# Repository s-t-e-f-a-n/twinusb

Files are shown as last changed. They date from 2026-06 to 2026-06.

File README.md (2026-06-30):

# H₂H³ | Twin USB Host Switch × Triple USB Hub (with OLED Telemetry)

**H₂H³** is a compact, STM32 microcontroller-driven USB 2.0 KVM switch and 3-port hub designed to maintain a clean, clutter-free workspace in modern home offices. It enables two computers to seamlessly share a single set of peripherals—like your keyboard, mouse, and flash drives—while delivering live voltage and current telemetry via an integrated OLED display.

<p align="center">
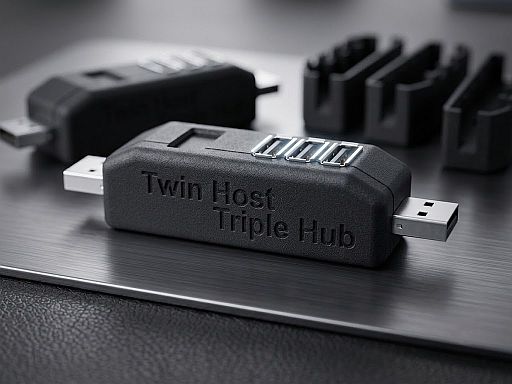
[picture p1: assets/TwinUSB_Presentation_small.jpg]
H₂H³ Presentation
  
</p>

> [!NOTE]
> **Project Status & Contribution:** This project is actively developed. The initial commit delivers roughly 90% of the core KVM switching and telemetry functionality in a fully functional prototype stage.
>
> To bring this project to a 100% polished release, **contributions from the open-source community are highly welcome!** Whether you want to optimize edge-case handling in the C++ firmware, implement new USB HID features, or help refine the documentation—feel free to open an issue or submit a Pull Request. Let's build this together!

* **Smart Break-Before-Make Switching:** Advanced, software-controlled VBUS and data line multiplexing ensures safe, glitch-free transitions and isolated power rails between both host PCs.
* **Integrated 3-Port Hub:** Built-in Genesys Logic controller expands a single shared USB connection into three downstream ports for your everyday desk peripherals.
* **🚀 Native Host-MCU Communication (Endless Use Cases!):** Unlike dumb KVM switches, the onboard STM32 MCU is wired directly into the hub as a **fourth USB peripheral device**. This allows the MCU to communicate natively with the active Host PC—opening up vast possibilities for custom PC desktop apps, background telemetry logging, hardware automation scripts, or even full USB HID keyboard/mouse emulation.
* **Live Telemetry Dashboard:** A crisp, integrated 64x32 pixel OLED display provides real-time insights by showing live bus voltage and precise current draw per port.
* **Ergonomic & Screw-less Enclosure:** Features a clean interface with a discreetly placed rear tactile button to prevent cable snags, all housed in a robust, snap-fit PA12-HP Nylon shell optimized for MJF 3D printing.
* **Modern C++ Firmware:** Driven by a powerful STM32G0 architecture running a modular, object-oriented C++ firmware stack with hardware-level overcurrent protection.

🖼️ Jump straight to the [Photo Gallery](#-photo-gallery).

🏪 **Hardware Available:** Skip the assembly line and grab a fully functional H₂H³ on [Tindie](https://www.tindie.com/products/43013/).

## 🔭 Background & Philosophy

H₂H³ represents a personal exploration into modern decentralized manufacturing and open-source engineering. It blends professional design principles with modern open-source software, AI-collaborative programming to refine the C++ firmware, and on-demand fabrication. The fact that an individual engineer can now prototype industrial-grade hardware using low-volume far-east manufacturing is nothing short of incredible.

To give back to the community, the full design files—spanning schematics, mechanics, and source code—are public domain under MIT and CERN Open Hardware licenses. It is intended strictly for educational use, and community-driven remixes are highly encouraged.

## 🛠️ Design Stack & Toolchain

The hardware, enclosure, and software for H₂H³ were designed using the following tools:

* **KiCad 9.0:** Schematic entry and PCB design for the 4-layer board.
* **FreeCAD 1.0:** 3D modeling of the screw-less, snap-fit two-part enclosure.
* **Firmware Toolchain:** Developed in modern modular C++ utilizing **STM32CubeMX** for hardware abstraction. Out of the box, the repository supports a dual-development workflow—you can build and debug the firmware seamlessly using either **Visual Studio Code (via CMake/Ninja)** or **STM32CubeIDE**, depending on your preferred environment.

---

## 🛠️ Hardware Specification

H₂H³ Hardware Block Diagram

* **Microcontroller:** ARM Cortex-M0+ 32-bit MCU (STM32G0B1KBU6, 64 MHz, 128 KB Flash, 144 KB RAM), integrated as a 4th peripheral on the hub.
* **USB 2.0 Hub Controller:** Genesys Logic GL852G.
* **Physical Interface:** * 2x USB-A Male (Host 1 / Host 2 connections)
  * 3x USB-A Female (Peripheral downstream ports)
* **Telemetry Sensors:** Continuous dual-host VBUS voltage sensing (enables auto-detection) and triple-peripheral current monitoring.
* **Switching Architecture:** Hybrid automatic/software-controlled VBUS muxer combined with hardware USB data line multiplexers.
* **User Interface:** 64x32 pixel OLED screen, 1x rear tactile switch button, and 1x fully programmable RGB LED (color and brightness).
* **Form Factor:** Ultra-compact desktop footprint (approx. 60 × 20 × 20 mm).

<table border="0" style="border: none; border-collapse: collapse;">
  <tr>
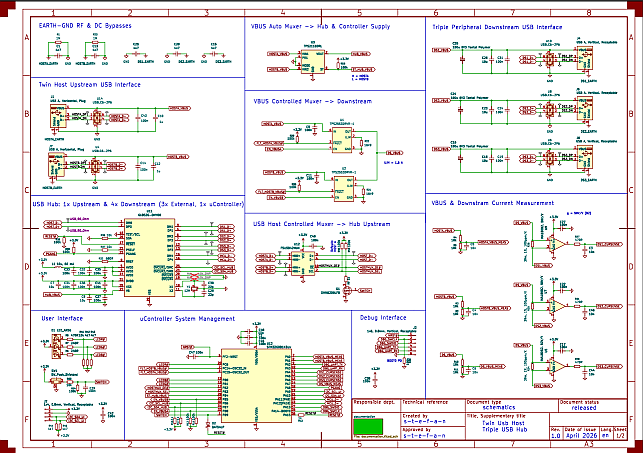
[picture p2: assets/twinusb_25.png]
    <td style="border: none; padding: 10px;"></td>
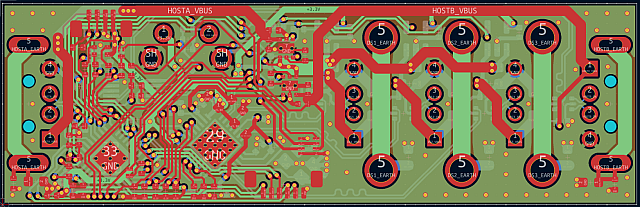
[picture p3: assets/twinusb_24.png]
    <td style="border: none; padding: 10px;"></td>
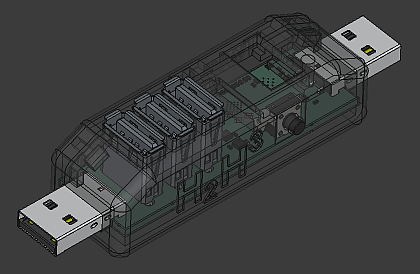
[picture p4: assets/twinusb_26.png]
    <td style="border: none; padding: 10px;"></td>
  </tr>
</table>

---

## 💻 Software & Firmware Architecture

The firmware is built using **STM32CubeMX** for hardware abstraction and written in **C/C++**.

### Advanced Features

* **Fully Modularized C/C++:** Source code is designed fully modular in C++ with support from the HAL in C automatically created by STM32CubeMX.
* **Optimized ADC Sampling:** Continuous monitoring of port power states with software-side calibration.
* **Overcurrent Detection:** Peripheral current draw of more than 1.5 A enters fault mode which the device resumes from by user confirmation.
* **UART Debug Console:** Retargeted `printf` over the STM32 USART2 or USB virtual COM port.
* **Binary Programming:** Powering on and holding switch button simultaneously enters the programming mode (STM32CubeProgrammer) which enables programming the ST32 integrated flash without the need for a hardware debugger

---

## 📂 Repository Structure

```text
twinusb/
├── assets/                  # Public media & documentation images
├── enclosure/               # Mechanical 3D CAD design (FreeCAD)
├── firmware/                # Production-ready STM32G0 C/C++ firmware
│   ├── App/                 # Core Application Logic (C++)
│   │   ├── Inc/             # Application Managers (Hub, Display, Sensors, UI)
│   │   └── Src/             # Implementation source code
│   ├── Core/                # Hardware peripheral initialization (ADC, I2C, GPIO)
│   ├── cmake/               # Toolchain configuration profiles
│   ├── Libs/                # Embedded drivers & hardware abstraction libraries
│   │   └── oled_waveshare/  # Low-level 0.49" 64x32 OLED display driver components
│   ├── Middlewares/         # STMicroelectronics USB Device Library stack
│   ├── Startup/             # Microcontroller boot vector assembly code
│   └── USB_Device/          # USB CDC Class configuration and descriptor maps
└── hardware/                # Electronics engineering files (KiCad)
    ├── lib_fp/              # Custom PCB footprint libraries (.pretty)
    └── lib_sch/             # Custom schematic component symbols
```

---

## ⚡ Getting Started & Building the Firmware

### 1. Cloning the Repository

```bash
git clone https://github.com/s-t-e-f-a-n/twinusb.git
cd twinusb

```

This project supports a **dual-development workflow**. You can build the firmware using either **VS Code (via CMake)** or the official **STM32CubeIDE**. Choose the workflow that best fits your environment. You do not need to use STM32CubeMX to build the project from scratch.

---

### Method A: Building with VS Code (Recommended)

This method uses CMake and Ninja/Make. It requires a local ARM GCC toolchain installed on your system.

#### Prerequisites

Ensure you have the following installed and available in your system's `PATH`:

* **ARM GNU Toolchain:** `arm-none-eabi-gcc`
* **Build Tools:** `CMake` and `Ninja` (or `Make`)
* **VS Code Extensions:**
* [CMake Tools](https://marketplace.visualstudio.com/items?itemName=ms-vscode.cmake-tools)
* [C/C++ Extension Pack](https://marketplace.visualstudio.com/items?itemName=ms-vscode.cpptools-extension-pack)

#### VS Code Setup & Build Steps

1. **Open Project:** Open the `firmware` directory in VS Code.
2. **Select Compiler Kit:** Open the Command Palette (`Ctrl+Shift+P` / `Cmd+Shift+P`), search for **`CMake: Select a Kit`**, and select your installed `arm-none-eabi` compiler.
3. **Select Build Variant:** Choose either `Debug` or `Release` from the CMake status bar at the bottom.
4. **Configure Project:** Run **`CMake: Configure`** from the Command Palette. This will clean-room generate your local `build/` directory with the correct absolute paths for your machine.
5. **Compile:** Click **`Build`** in the status bar or press `F7`.

---

### Method B: Building with STM32CubeIDE

STM32CubeIDE is an all-in-one Eclipse-based IDE that includes its own compiler toolchain and internal build system out of the box.

#### STM32CubeIDE Setup & Build Steps

1. **Import Project:**

* Open STM32CubeIDE.
* Go to `File` ➔ `Open Projects from Filesystem...`
* Select `Directory` ➔ `Choose twinusb folder` and click *Select Folder*.
* Click *Finish*.

2. **Index Project:** Wait a few moments for the IDE to finish indexing the source files.

3. **Compile:** Click the **Hammer icon (Build)** in the top toolbar, or press `Ctrl+B` (`Cmd+B` on macOS).

---

### ⚠️ Crucial Note on Code Generation (C++ Integration)

The core application logic of this project is written in modern **C++** and lives inside the `App/` directory (`App/Src` and `App/Inc`), keeping it cleanly decoupled from the autogenerated ST HAL layer.

If you decide to open the `twinusb.stm32.ioc` file to modify pinouts or peripherals via STM32CubeMX and click **"Generate Code"**, the tools will reset the project workspace to ST's default pure-C template.

**If your IDE loses track of the C++ files after code generation, fix it manually:**

* **In STM32CubeIDE:** Right-click the project ➔ `Properties` ➔ `C/C++ General` ➔ `Paths and Symbols`.
* Under **Includes**, re-add the `App/Inc` directory.
* Under **Source Location**, re-add the `App/Src` directory.

* **In VS Code:** Simply run **`CMake: Delete Cache and Reconfigure`** from the Command Palette to force CMake to re-scan the file structure.

---

## 🏭 Sourcing the Hardware

### PCB & Assembly

The schematics and PCB layout are located in the `/hardware` folder, designed in KiCad and optimized for automated assembly (PCBA) via services like JLCPCB.

### Enclosure

Print the shell components located in the `/enclosure` folder. Nylon (SLS/MJF technique) is highly recommended for that professional, textured matte finish and mechanical durability.

---

## 📸 Photo Gallery

| &nbsp; | &nbsp; | &nbsp; |
| :---: | :---: | :---: |
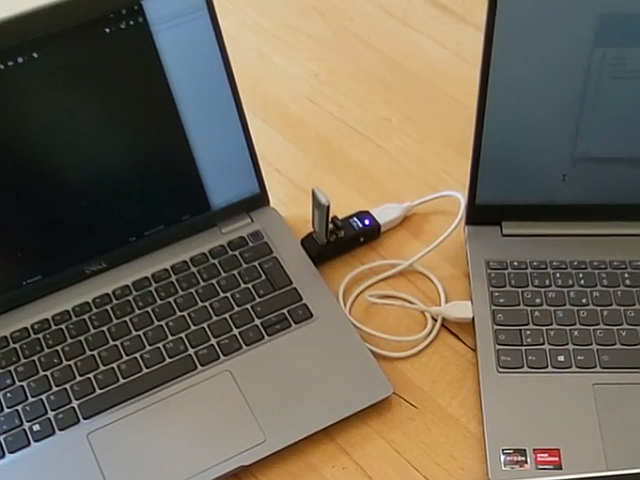
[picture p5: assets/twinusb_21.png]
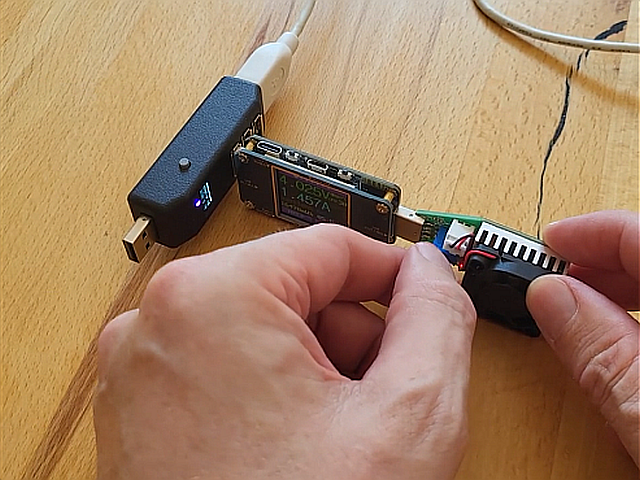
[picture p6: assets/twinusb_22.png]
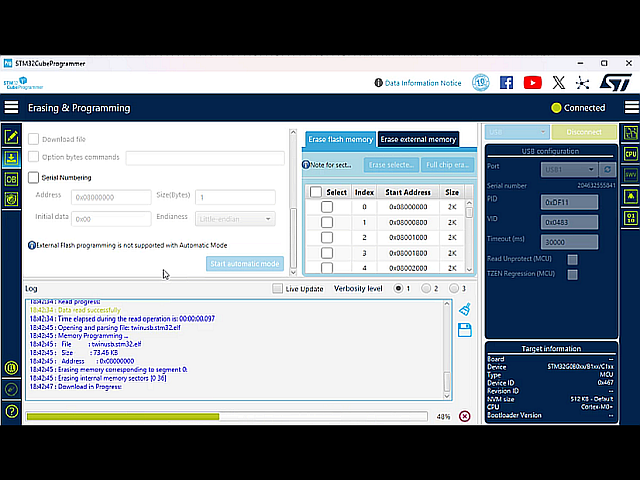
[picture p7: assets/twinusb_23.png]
|  |  |  |
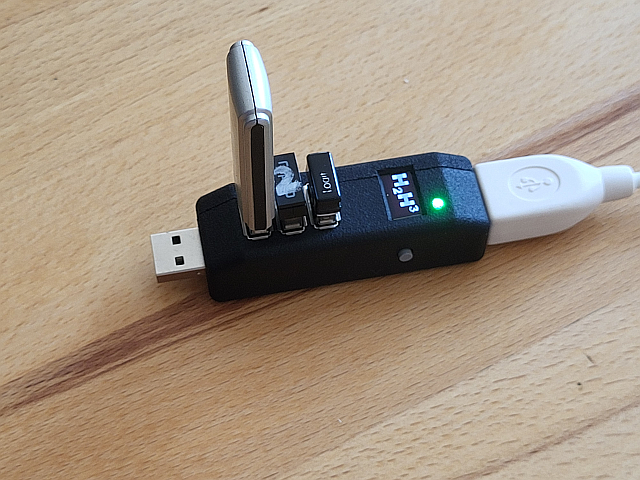
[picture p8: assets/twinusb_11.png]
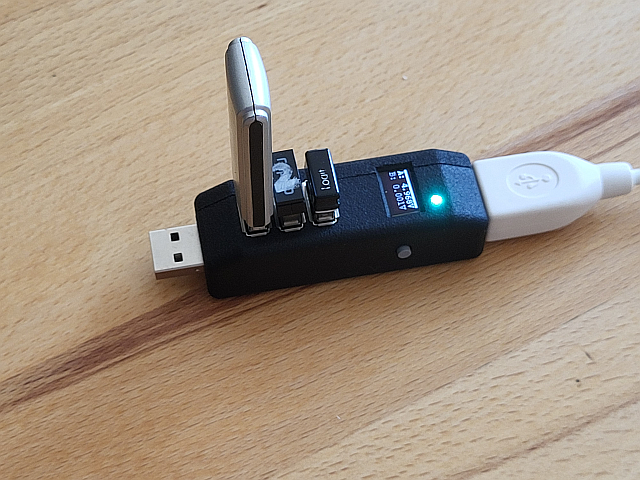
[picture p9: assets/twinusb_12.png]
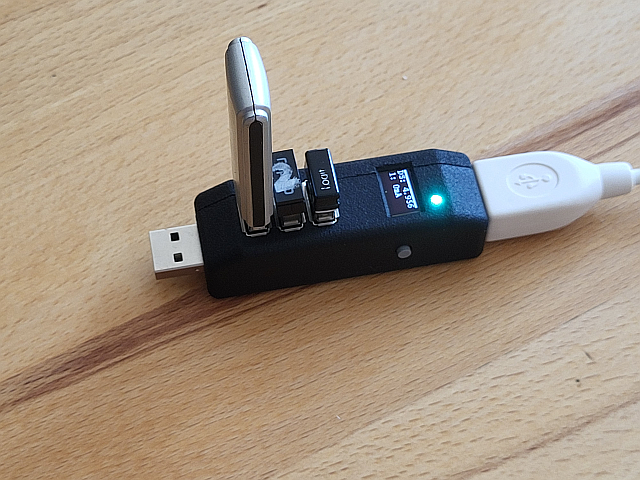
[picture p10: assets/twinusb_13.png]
|  |  |  |
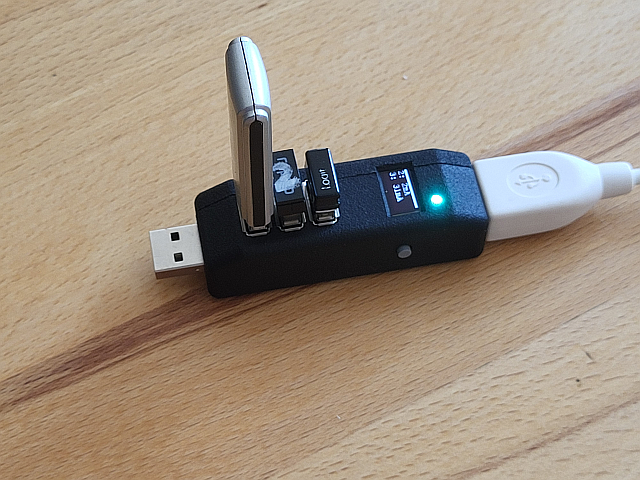
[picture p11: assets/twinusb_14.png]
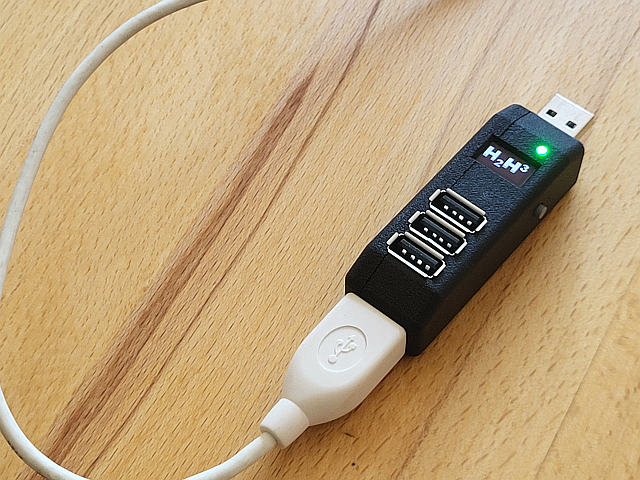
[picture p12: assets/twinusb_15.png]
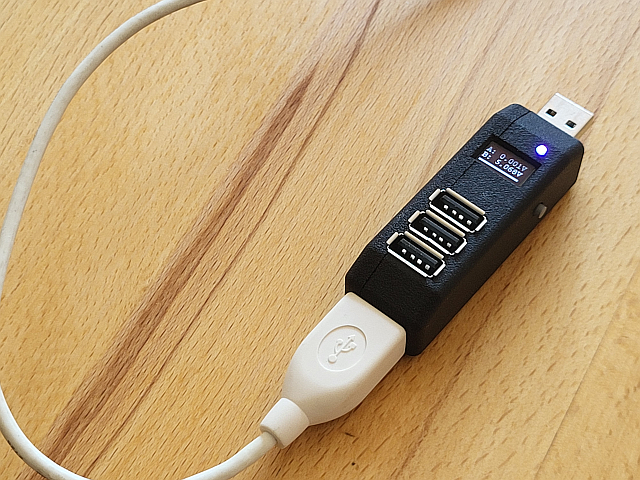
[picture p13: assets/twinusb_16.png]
|  |  |  |
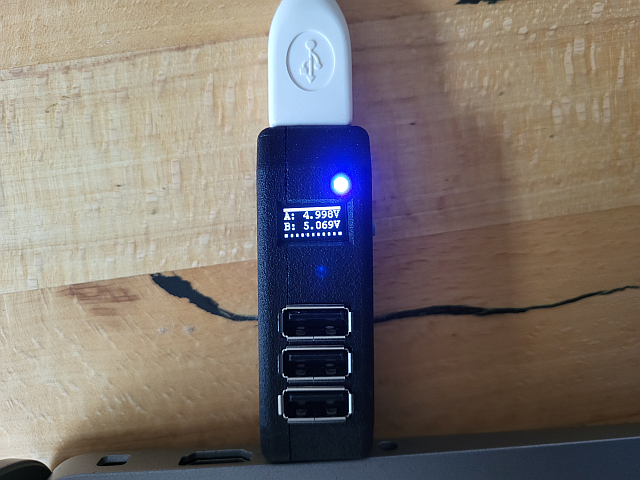
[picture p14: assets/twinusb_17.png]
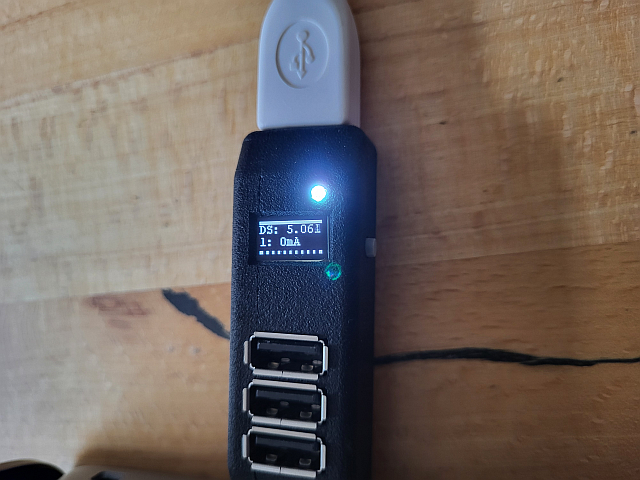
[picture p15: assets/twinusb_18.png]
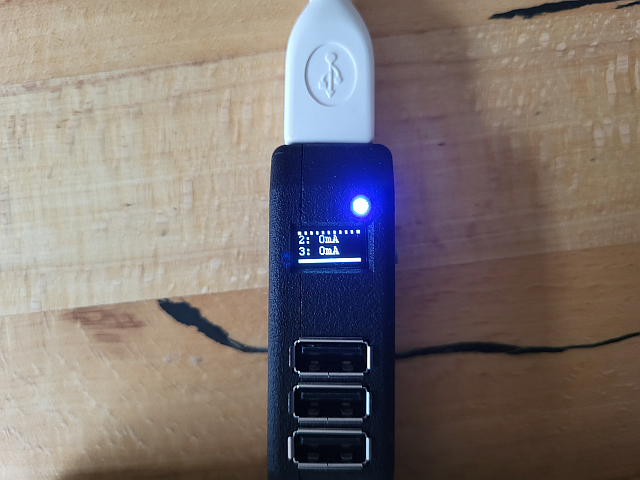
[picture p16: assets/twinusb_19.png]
|  |  |  |
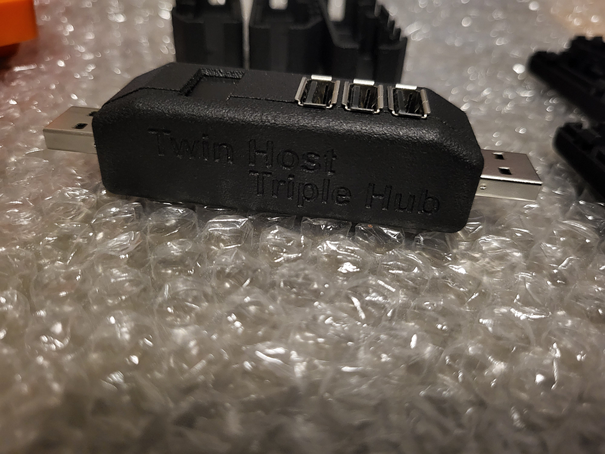
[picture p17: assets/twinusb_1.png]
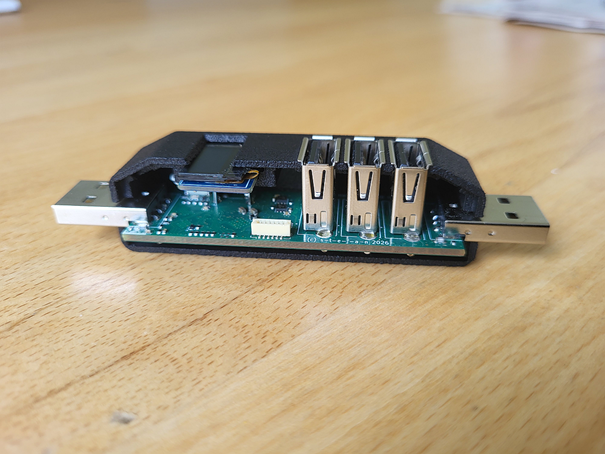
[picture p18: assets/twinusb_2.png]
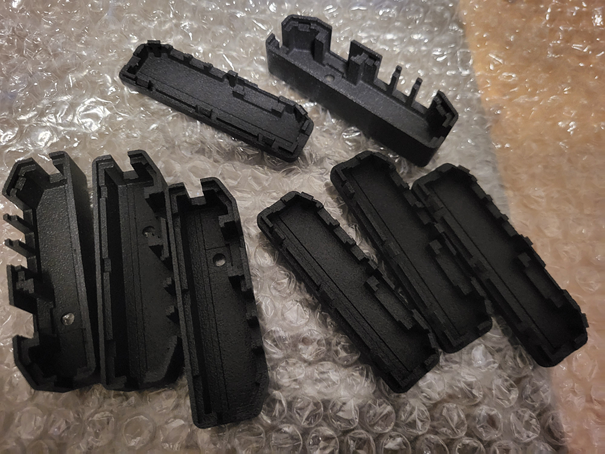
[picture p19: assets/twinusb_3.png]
|  |  |  |
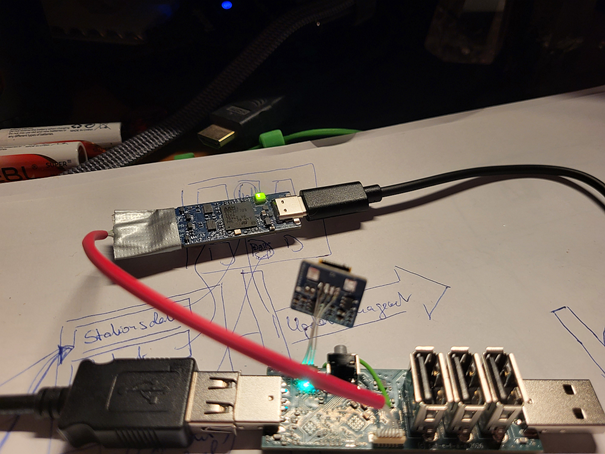
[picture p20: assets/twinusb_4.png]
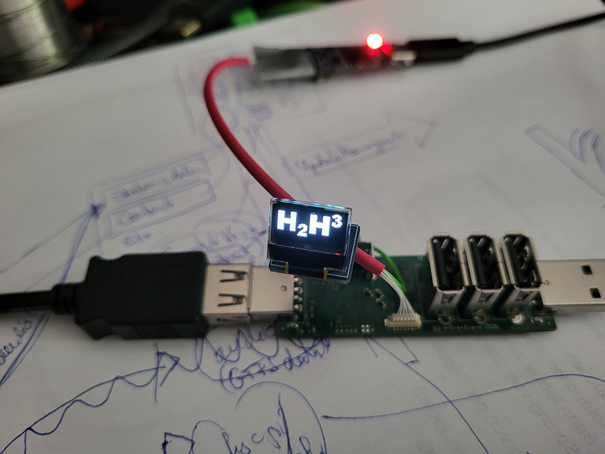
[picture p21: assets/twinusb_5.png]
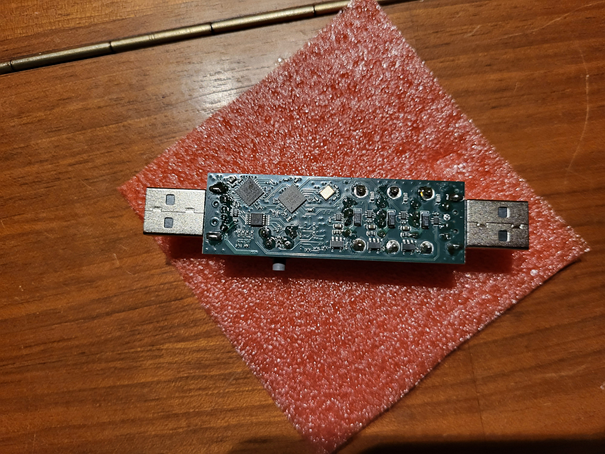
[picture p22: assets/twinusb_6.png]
|  |  |  |
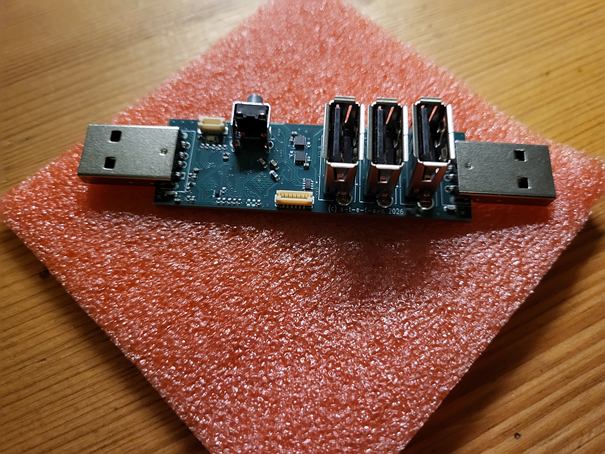
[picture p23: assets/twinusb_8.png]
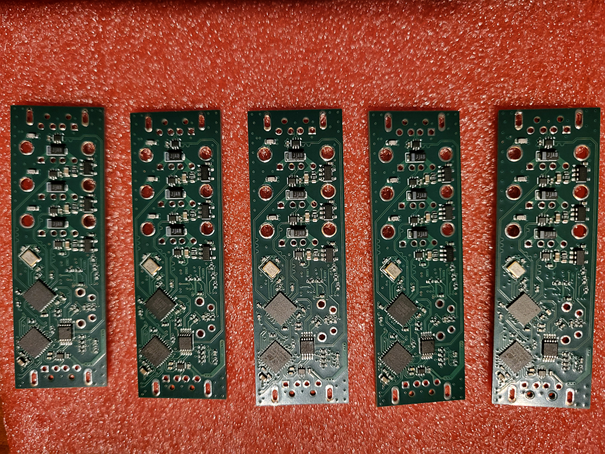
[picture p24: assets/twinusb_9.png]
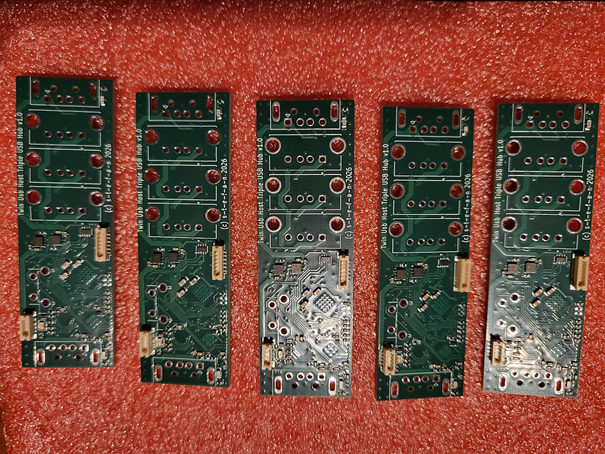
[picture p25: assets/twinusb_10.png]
|  |  |  |

---

## ⚖️ License

This project is licensed under different Open Source licenses depending on the component:

* 💻 **Firmware & Software:** Licensed under the [MIT License](firmware/LICENSE)
  *(Permissive, commercial-friendly software license)*
* 🔌 **Hardware (PCB & Schematics):** Licensed under the [CERN-OHL-W v2](hardware/LICENSE)
  *(CERN Open Hardware Licence - Weak Copyleft)*
* 📦 **Enclosure (Mechanical CAD):** Licensed under the [CERN-OHL-W v2](enclosure/LICENSE)
  *(CERN Open Hardware Licence - Weak Copyleft)*

All components are copyrighted © 2026 by **s-t-e-f-a-n** who developed them with ❤️

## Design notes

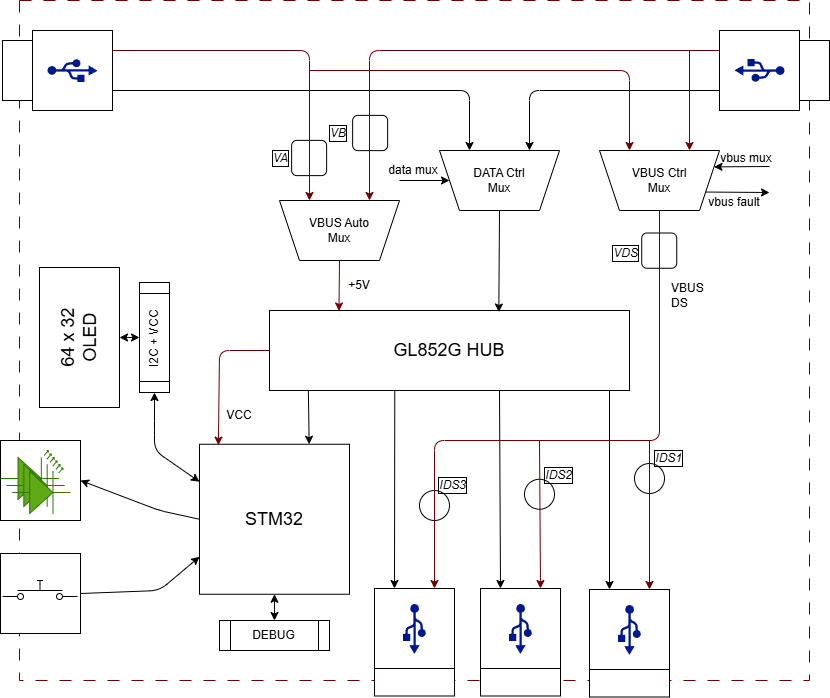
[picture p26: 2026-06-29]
assets/twinusb_hardware.png

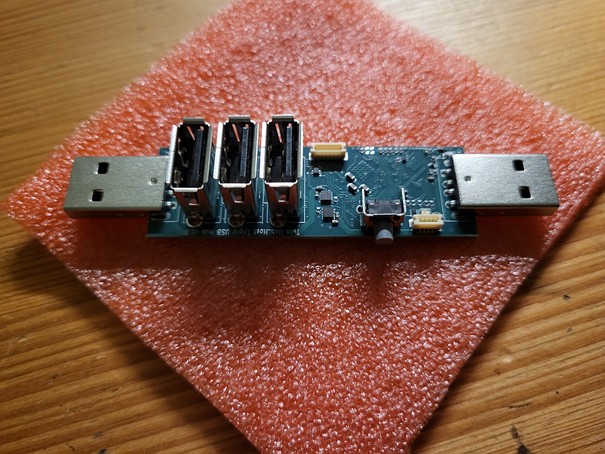
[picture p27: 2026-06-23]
assets/twinusb_7.png

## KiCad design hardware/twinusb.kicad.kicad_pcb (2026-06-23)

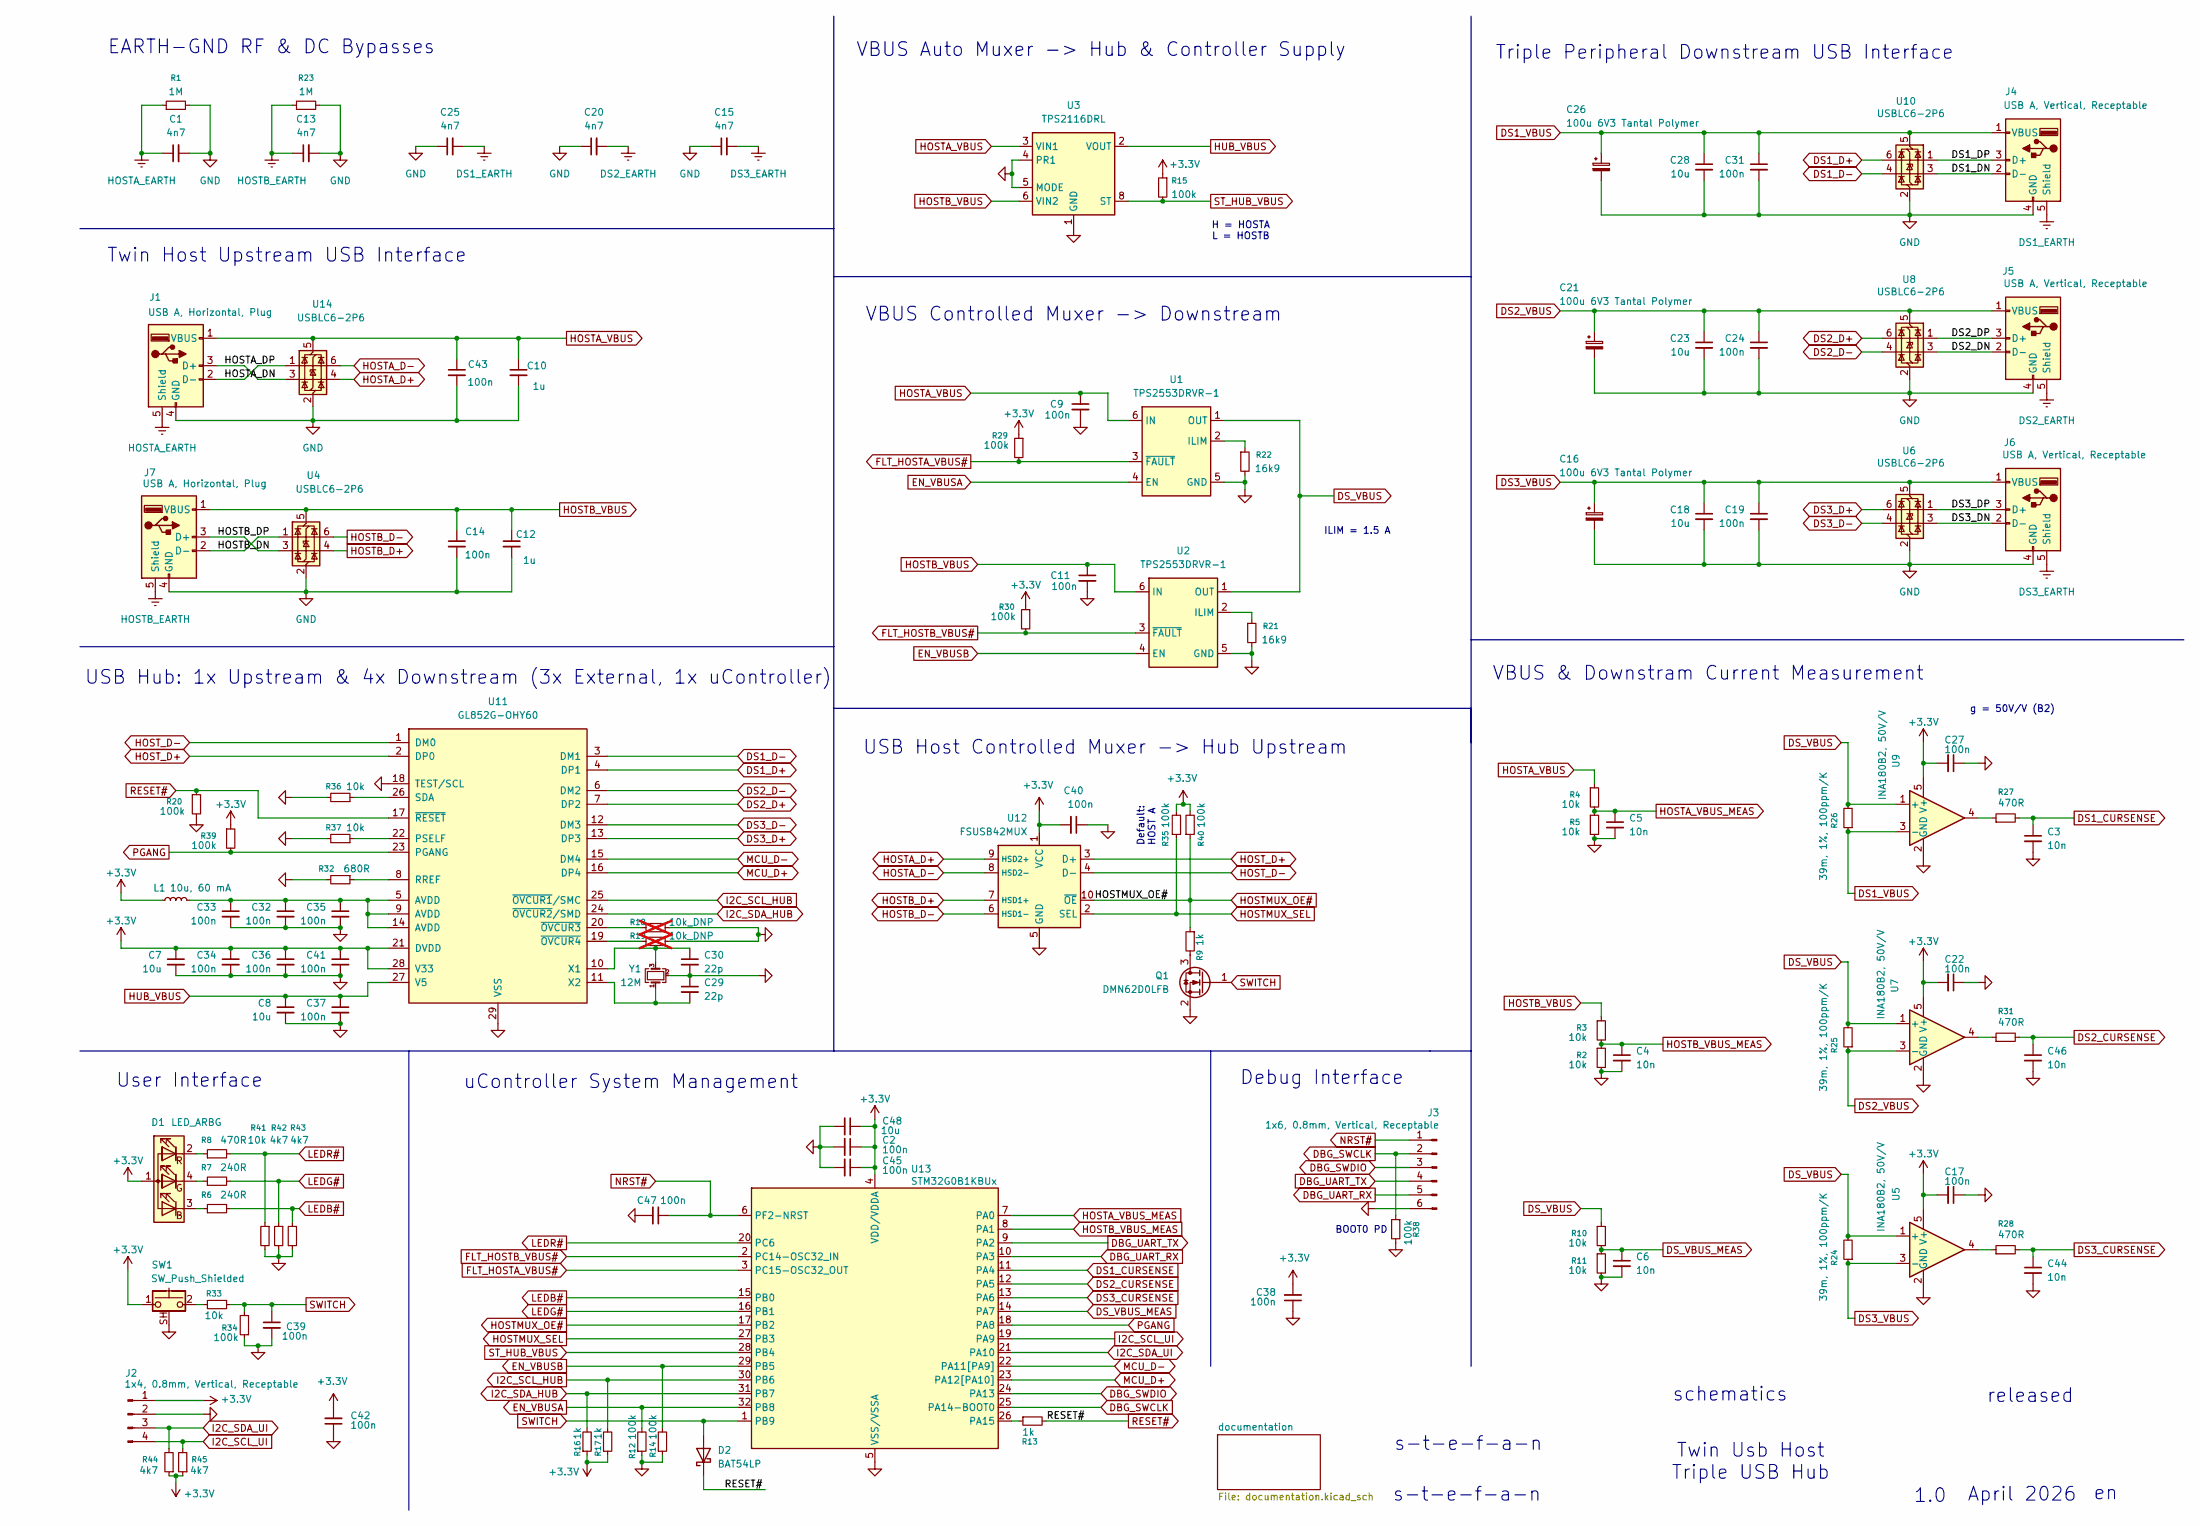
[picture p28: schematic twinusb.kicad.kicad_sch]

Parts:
C1, C13, C15, C20, C25: 4n7; C_0603_1608Metric; LCSC PN C85980
C2, C9, C11, C14, C17, C19, C22, C24, C27, C31, C32, C33, C34, C35, C36, C37, C38, C39, C40, C41, C42, C43, C45, C47: 100n; C_0402_1005Metric; LCSC PN C307331
C3, C4, C5, C6, C44, C46: 10n; C_0402_1005Metric; LCSC PN C15195
C7, C8, C18, C23, C28, C48: 10u; C_0603_1608Metric; LCSC PN C19702
C10, C12: 1u; C_0402_1005Metric; LCSC PN C52923
C16, C21, C26: 100u 6V3 Tantal Polymer; CP_EIA-3216-18_Kemet-A; MPN T520A107M006ATE070; LCSC PN C561794
C29, C30: 22p; C_0402_1005Metric; LCSC PN C1555
D1: LED_ARBG; LED_RGB_Kingbright_APHF1608LSEEQBDZGKC; MPN APHF1608LSEEQBDZGKC; LCSC PN C3019171
D2: BAT54LP; Diodes_DFN1006-2; MPN BAT54LP; LCSC PN C134410
J1, J7: USB A, Horizontal, Plug; USB_A_Horizontal_THT; MPN UP2-AH-1-TH; Mouser PN 490-UP2-AH-1-TH
J2: 1x4, 0.8mm, Vertical, Receptable; JST_SUR_BM04B-SURS-TF_1x04-1MP_P0.80mm_Vertical; MPN BM04B-SURS-TF; LCSC PN C495551
J3: 1x6, 0.8mm, Vertical, Receptable; JST_SUR_BM06B-SURS-TF_1x06-1MP_P0.80mm_Vertical; MPN BM06B-SURS-TF; LCSC PN C5118712
J4, J5, J6: USB A, Vertical, Receptable; USB_A_Vertical_AMPHENOL_UE27AE54100; MPN UE27-AE54-100; Mouser PN 523-UE27-AE54-100
L1: 10u, 60 mA; L_0603_1608Metric; MPN MLZ1608N100LTD25; LCSC PN C307750
Q1: DMN62D0LFB; DFN1006-3; MPN DMN62D0LFB; LCSC PN C397945
R1, R23: 1M; R_0402_1005Metric; LCSC PN C26083
R2, R3, R4, R5, R10, R11, R33, R36, R37, R41: 10k; R_0402_1005Metric; LCSC PN C60490
R6, R7: 240R; R_0402_1005Metric; LCSC PN C114755
R8, R27, R28, R31: 470R; R_0402_1005Metric; LCSC PN C25117
R9, R13, R16, R17: 1k; R_0402_1005Metric; LCSC PN C11702
R12, R14, R15, R20, R29, R30, R34, R35, R38, R39, R40: 100k; R_0402_1005Metric; LCSC PN C25741
R18, R19: 10k_DNP; R_0402_1005Metric; LCSC PN C60490; not fitted
R21, R22: 16k9; R_0402_1005Metric; LCSC PN C25858
R24, R25, R26: 39m, 1%, 100ppm/K; R_0603_1608Metric; MPN PE0603FRF7T0R039L; LCSC PN C858571
R32: 680R; R_0402_1005Metric; LCSC PN C25130
R42, R43, R44, R45: 4k7; R_0402_1005Metric; LCSC PN C25900
SW1: SW_Push_Shielded; SW_Tactile_SPST_Angled_PTS645Vx58-2LFS; MPN PTS645VH58-2 LFS; Mouser PN 611-PTS645VH582
U1, U2: TPS2553DRVR-1; WSON-6-1EP_2x2mm_P0.65mm_EP1x1.6mm_ThermalVias; MPN TPS2553DRVR-1; LCSC PN C411878
U3: TPS2116DRL; SOT-583-8; MPN TPS2116DRLR; LCSC PN C3235557
U4, U6, U8, U10, U14: USBLC6-2P6; SOT-666; MPN USBLC6-2P6; LCSC PN C15999
U5, U7, U9: INA180B2, 50V/V; SOT-23-5; MPN INA180B2IDBVR; LCSC PN C2861539
U11: GL852G-OHY60; QFN-28-1EP_5x5mm_P0.5mm_EP3.75x3.75mm_ThermalVias; MPN GL852G-OHY60; LCSC PN C7501404
U12: FSUSB42MUX; MSOP-10_3x3mm_P0.5mm; MPN FSUSB42MUX; LCSC PN C11355
U13: STM32G0B1KBUx; QFN-32-1EP_5x5mm_P0.5mm_EP3.45x3.45mm_ThermalVias; MPN STM32G0B1KBU6; LCSC PN C5159549
Y1: 12M; Crystal_SMD_3225-4Pin_3.2x2.5mm; MPN X322512MSB4SI; LCSC PN C9002

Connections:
+3.3V: C2.1, C7.1, C17.2, C22.2, C27.2, C34.1, C36.1, C38.2, C40.2, C41.1, C42.2, C45.1, C48.1, D1.1 (A), J2.1, L1.1, R15.1, R16.1, R17.1, R29.1, R30.1, R35.2, R39.1, R40.2, R44.1, R45.1, SW1.1, U5.5 (V+), U7.5 (V+), U9.5 (V+), U11.21 (DVDD), U11.28 (V33), U12.1 (VCC), U13.4 (VDD/VDDA)
/DS1_DN: J4.2 (D-), U10.3 (I/O2)
/DS1_DP: J4.3 (D+), U10.1 (I/O1)
/DS2_DN: J5.2 (D-), U8.3 (I/O2)
/DS2_DP: J5.3 (D+), U8.1 (I/O1)
/DS3_DN: J6.2 (D-), U6.3 (I/O2)
/DS3_DP: J6.3 (D+), U6.1 (I/O1)
/HOSTA_DN: J1.2 (D-), U14.1 (I/O1)
/HOSTA_DP: J1.3 (D+), U14.3 (I/O2)
/HOSTB_DN: J7.2 (D-), U4.1 (I/O1)
/HOSTB_DP: J7.3 (D+), U4.3 (I/O2)
DBG_SWCLK: J3.2, R38.1, U13.25 (PA14-BOOT0)
DBG_SWDIO: J3.3, U13.24 (PA13)
DBG_UART_RX: J3.5, U13.10 (PA3)
DBG_UART_TX: J3.4, U13.9 (PA2)
DS1_CURSENSE: C3.1, R27.2, U13.11 (PA4)
DS1_D+: U10.6 (I/O1), U11.4 (DP1)
DS1_D-: U10.4 (I/O2), U11.3 (DM1)
DS1_EARTH: C25.2, J4.5 (Shield)
DS1_VBUS: C26.1, C28.1, C31.1, J4.1 (VBUS), R26.1, U9.3 (-), U10.5 (VBUS)
DS2_CURSENSE: C46.1, R31.2, U13.12 (PA5)
DS2_D+: U8.6 (I/O1), U11.7 (DP2)
DS2_D-: U8.4 (I/O2), U11.6 (DM2)
DS2_EARTH: C20.2, J5.5 (Shield)
DS2_VBUS: C21.1, C23.1, C24.1, J5.1 (VBUS), R25.1, U7.3 (-), U8.5 (VBUS)
DS3_CURSENSE: C44.1, R28.2, U13.13 (PA6)
DS3_D+: U6.6 (I/O1), U11.13 (DP3)
DS3_D-: U6.4 (I/O2), U11.12 (DM3)
DS3_EARTH: C15.2, J6.5 (Shield)
DS3_VBUS: C16.1, C18.1, C19.1, J6.1 (VBUS), R24.1, U5.3 (-), U6.5 (VBUS)
DS_VBUS: R10.1, R24.2, R25.2, R26.2, U1.1 (OUT), U2.1 (OUT), U5.1 (+), U7.1 (+), U9.1 (+)
DS_VBUS_MEAS: C6.1, R10.2, R11.1, U13.14 (PA7)
EN_VBUSA: R12.2, U1.4 (EN), U13.32 (PB8)
EN_VBUSB: R14.2, U2.4 (EN), U13.29 (PB5)
FLT_HOSTA_VBUS#: R29.2, U1.3 (~FAULT), U13.3 (PC15-OSC32_OUT)
FLT_HOSTB_VBUS#: R30.2, U2.3 (~FAULT), U13.2 (PC14-OSC32_IN)
GND: C1.2, C2.2, C3.2, C4.2, C5.2, C6.2, C7.2, C8.2, C9.2, C10.2, C11.2, C12.2, C13.2, C14.2, C15.1, C16.2, C17.1, C18.2, C19.2, C20.1, C21.2, C22.1, C23.2, C24.2, C25.1, C26.2, C27.1, C28.2, C29.1, C30.2, C31.2, C32.2, C33.2, C34.2, C35.2, C36.2, C37.2, C38.1, C39.2, C40.1, C41.2, C42.1, C43.2, C44.2, C45.2, C46.2, C47.2, C48.2, J1.4 (GND), J2.2, J3.6, J4.4 (GND), J5.4 (GND), J6.4 (GND), J7.4 (GND), Q1.2 (S), R1.2, R2.2, R5.2, R11.2, R12.1, R14.1, R18.1, R19.1, R20.2, R21.2, R22.2, R23.2, R32.2, R34.1, R36.2, R37.2, R38.2, R41.2, R42.2, R43.2, SW1.SH (B), U1.5 (GND), U1.7 (TP), U2.5 (GND), U2.7 (TP), U3.1 (GND), U3.4 (PR1), U3.5 (MODE), U4.2 (GND), U5.2 (GND), U6.2 (GND), U7.2 (GND), U8.2 (GND), U9.2 (GND), U10.2 (GND), U11.18 (TEST/SCL), U11.29 (VSS), U12.5 (GND), U13.5 (VSS/VSSA), U13.33 (VSS), U14.2 (GND), Y1.2 (G), Y1.4 (G)
HOSTA_D+: U12.9 (HSD2+), U14.4 (I/O2)
HOSTA_D-: U12.8 (HSD2-), U14.6 (I/O1)
HOSTA_EARTH: C1.1, J1.5 (Shield), R1.1
HOSTA_VBUS: C9.1, C10.1, C43.1, J1.1 (VBUS), R4.1, U1.6 (IN), U3.3 (VIN1), U14.5 (VBUS)
HOSTA_VBUS_MEAS: C5.1, R4.2, R5.1, U13.7 (PA0)
HOSTB_D+: U4.4 (I/O2), U12.7 (HSD1+)
HOSTB_D-: U4.6 (I/O1), U12.6 (HSD1-)
HOSTB_EARTH: C13.1, J7.5 (Shield), R23.1
HOSTB_VBUS: C11.1, C12.1, C14.1, J7.1 (VBUS), R3.1, U2.6 (IN), U3.6 (VIN2), U4.5 (VBUS)
HOSTB_VBUS_MEAS: C4.1, R2.1, R3.2, U13.8 (PA1)
HOSTMUX_OE#: R9.1, R40.1, U12.10 (~OE), U13.17 (PB2)
HOSTMUX_SEL: R35.1, U12.2 (SEL), U13.27 (PB3)
HOST_D+: U11.2 (DP0), U12.3 (D+)
HOST_D-: U11.1 (DM0), U12.4 (D-)
HUB_VBUS: C8.1, C37.1, U3.2 (VOUT), U3.7 (VOUT), U11.27 (V5)
I2C_SCL_HUB: R17.2, U11.25 (~OVCUR1/SMC), U13.30 (PB6)
I2C_SCL_UI: J2.4, R45.2, U13.19 (PA9)
I2C_SDA_HUB: R16.2, U11.24 (~OVCUR2/SMD), U13.31 (PB7)
I2C_SDA_UI: J2.3, R44.2, U13.21 (PA10)
LEDB#: R6.2, R43.1, U13.15 (PB0)
LEDG#: R7.2, R42.1, U13.16 (PB1)
LEDR#: R8.2, R41.1, U13.20 (PC6)
MCU_D+: U11.16 (DP4), U13.23 (PA12[PA10])
MCU_D-: U11.15 (DM4), U13.22 (PA11[PA9])
NRST#: C47.1, J3.1, U13.6 (PF2-NRST)
unnamed: C32.1, C33.1, C35.1, L1.2, U11.5 (AVDD), U11.9 (AVDD), U11.14 (AVDD)
unnamed: D1.3 (BK), R6.1
unnamed: D1.4 (GK), R7.1
unnamed: D1.2 (RK), R8.1
unnamed: Q1.3 (D), R9.2
unnamed: R27.1, U9.4
unnamed: R28.1, U5.4
unnamed: R31.1, U7.4
unnamed: R33.2, SW1.2
unnamed: R22.1, U1.2 (ILIM)
unnamed: R21.1, U2.2 (ILIM)
unnamed: R37.1, U11.22 (PSELF)
unnamed: R32.1, U11.8 (RREF)
unnamed: R36.1, U11.26 (SDA)
unnamed: C30.1, U11.10 (X1), Y1.3
unnamed: C29.2, U11.11 (X2), Y1.1
unnamed: R18.2, U11.20 (~OVCUR3)
unnamed: R19.2, U11.19 (~OVCUR4)
unnamed: R13.1, U13.26 (PA15)
PGANG: R39.2, U11.23 (PGANG), U13.18 (PA8)
RESET#: D2.1 (K), R13.2, R20.1, U11.17 (~RESET)
ST_HUB_VBUS: R15.2, U3.8 (ST), U13.28 (PB4)
SWITCH: C39.1, D2.2 (A), Q1.1 (G), R33.1, R34.2, U13.1 (PB9)

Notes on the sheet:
ILIM = 1.5 A
s-t-e-f-a-n
USB Host Controlled Muxer -> Hub Upstream
Triple Peripheral Downstream USB Interface
1.0
schematics
BOOT0 PD
H = HOSTA L = HOSTB
VBUS & Downstram Current Measurement
VBUS Auto Muxer -> Hub & Controller Supply
April 2026
User Interface
EARTH-GND RF & DC Bypasses
Twin Host Upstream USB Interface
uController System Management
Default: HOST A
Debug Interface
Twin Usb Host Triple USB Hub
USB Hub: 1x Upstream & 4x Downstream (3x External, 1x uController)
VBUS Controlled Muxer -> Downstream
released
g = 50V/V (B2)

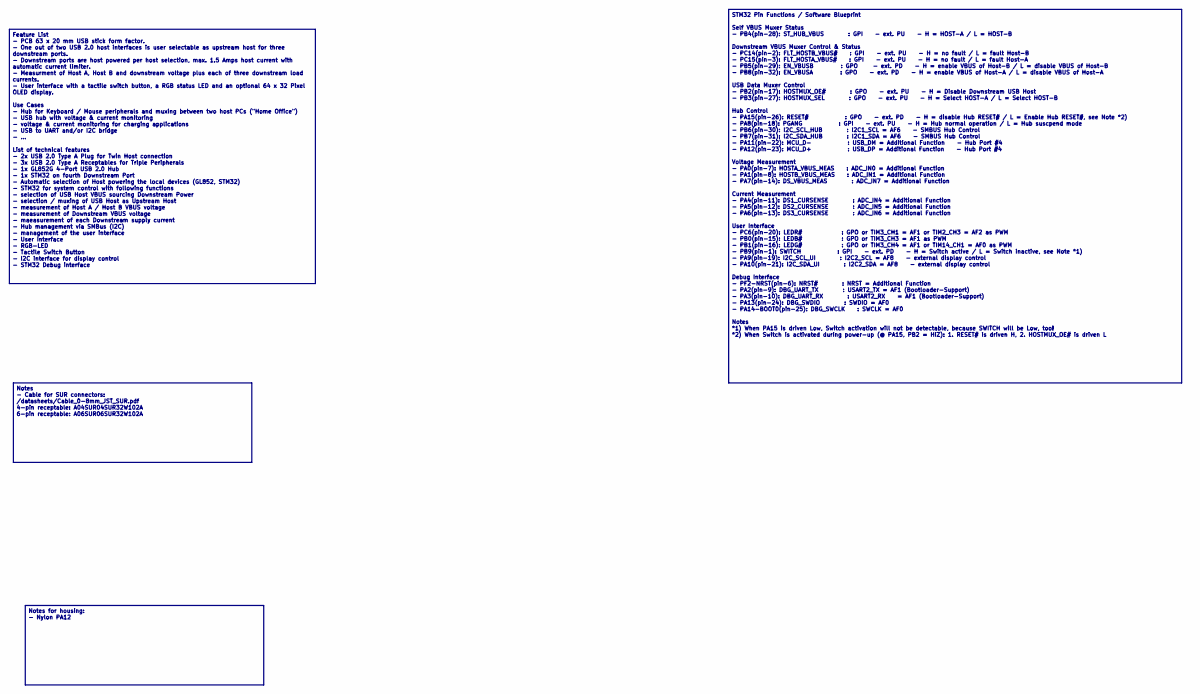
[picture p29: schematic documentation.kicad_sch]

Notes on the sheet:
Notes - Cable for SUR connectors: /datasheets/Cable_0-8mm_JST_SUR.pdf 4-pin receptable: A04SUR04SUR32W102A 6-pin receptable: A06SUR06SUR32W102A
STM32 Pin Functions / Software Blueprint Self VBUS Muxer Status - PB4(pin-28): ST_HUB_VBUS : GPI - ext. PU - H = HOST-A / L = HOST-B Downstream VBUS Muxer Control & Status - PC14(pin-2): FLT_HOSTB_VBUS# : GPI - ext. PU - H = no fault / L = fault Host-B - PC15(pin-3): FLT_HOSTA_VBUS# : GPI - ext. PU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
Feature List - PCB 63 x 20 mm USB stick form factor. - One out of two USB 2.0 host interfaces is user selectable as upstream host for three downstream ports. - Downstream ports are host powered per host selection, max. 1.5 Amps host current with automatic current limiter. - Measurment of Host A, Ho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
Notes for housing: - Nylon PA12

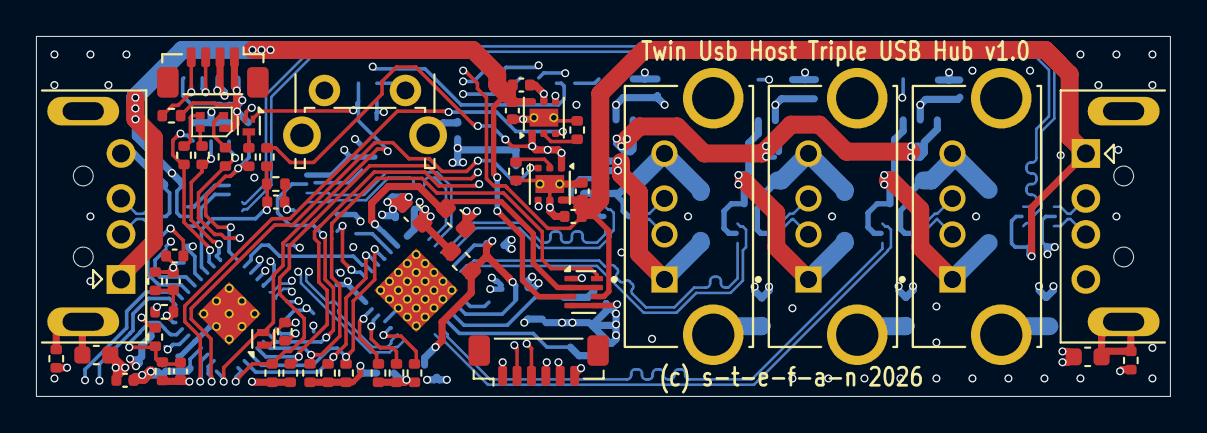
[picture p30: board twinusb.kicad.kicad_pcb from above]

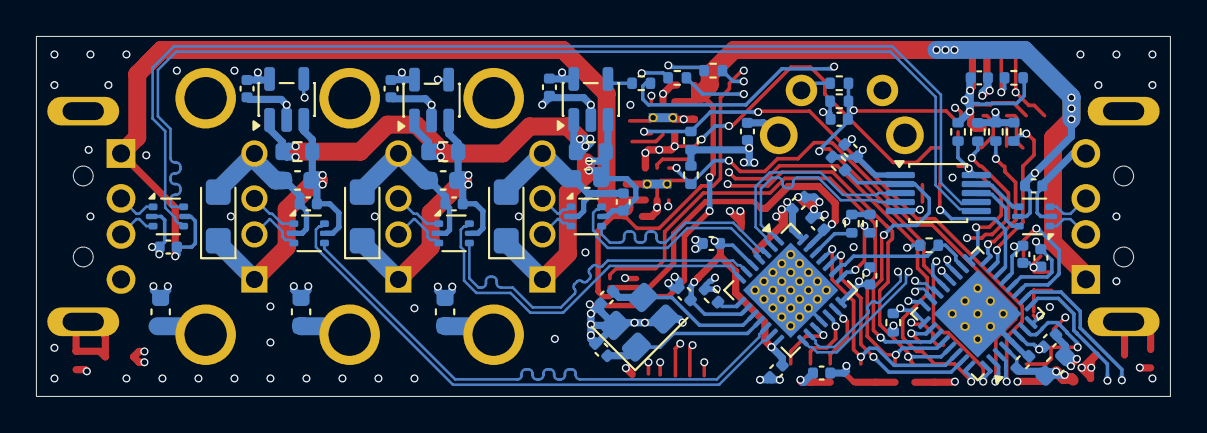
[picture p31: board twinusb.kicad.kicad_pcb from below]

Board: 4 copper layers, 63.0 x 20.0 mm, 120 parts (68 on the bottom side), 85 nets.

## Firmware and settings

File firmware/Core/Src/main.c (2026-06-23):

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
/* Includes ------------------------------------------------------------------*/
#include "main.h"
#include "adc.h"
#include "i2c.h"
#include "tim.h"
#include "usart.h"
#include "usb_device.h"
#include "gpio.h"

/* USER CODE BEGIN Includes */
#include "AppMain.hpp"
#include "Bootloader.hpp"
#include <stdio.h>
/* USER CODE END Includes */


void SystemClock_Config(void);
/**
  * @brief  The application entry point.
  * @retval int
  */
int main(void)
{

  /* MCU Configuration--------------------------------------------------------*/

  /* Reset of all peripherals, Initializes the Flash interface and the Systick. */
  HAL_Init();

  /* USER CODE BEGIN Init */
  CheckBootloaderSwitch();
  /* USER CODE END Init */

  /* Configure the system clock */
  SystemClock_Config();

  /* Initialize all configured peripherals */
  MX_GPIO_Init();
  MX_ADC1_Init();
  MX_I2C1_Init();
  MX_I2C2_Init();
  MX_USART2_UART_Init();
  MX_USB_Device_Init();
  MX_TIM3_Init();
  MX_TIM14_Init();
  /* USER CODE BEGIN 2 */
  extern uint8_t debugRxByte;

  // 1. Clear any pending error flags (like ORE) that block the UART
  __HAL_UART_CLEAR_FLAG(&huart2, UART_CLEAR_OREF | UART_CLEAR_NEF);

  // 2. Dummy read RDR to clear the RXNE (Read Data Register Not Empty) flag
  volatile uint32_t tmpreg = USART2->RDR;
  (void)tmpreg; // Prevent "unused variable" compiler warning

  // 3. Enable the single-byte UART receiver interrupt in a clean state
  HAL_UART_Receive_IT(&huart2, &debugRxByte, 1);

  // Start the timer for LED animation
  extern TIM_HandleTypeDef htim14;
  HAL_TIM_Base_Start_IT(&htim14);

  AppMain();
  /* USER CODE END 2 */

  /* Infinite loop */
  /* USER CODE BEGIN WHILE */
  while (1)
  {
    /* USER CODE END WHILE */

    /* USER CODE BEGIN 3 */
  }
  /* USER CODE END 3 */
}

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
/* USER CODE BEGIN 4 */
uint8_t debugRxByte;

// Compiles the ISR hooks whenever the developer selects the UART console path
#if (CONSOLE_TYPE == CONSOLE_UART)
void HAL_UART_RxCpltCallback(UART_HandleTypeDef *huart) {
    if (huart->Instance == USART2) {
        extern void Console_OnCharReceived(uint8_t byte);
        Console_OnCharReceived(debugRxByte);
        HAL_UART_Receive_IT(&huart2, &debugRxByte, 1);
    }
}

void HAL_UART_ErrorCallback(UART_HandleTypeDef *huart) {
    if (huart->Instance == USART2) {
        __HAL_UART_CLEAR_FLAG(huart, UART_CLEAR_OREF | UART_CLEAR_NEF | UART_CLEAR_FEF);
        HAL_UART_Receive_IT(huart, &debugRxByte, 1);
    }
}
#endif
/* USER CODE END 4 */
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


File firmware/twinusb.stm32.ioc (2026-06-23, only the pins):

Mcu.UserName=STM32G0B1KBUx
PA0.GPIO_Label=HOSTA_VBUS_MEAS
PA0.Signal=ADC1_IN0
PA1.GPIO_Label=HOSTB_VBUS_MEAS
PA1.Signal=ADC1_IN1
PA10.GPIO_Label=I2C_SDA_UI
PA10.Signal=I2C2_SDA
PA13.Signal=SYS_SWDIO
PA14-BOOT0.Signal=SYS_SWCLK
PA15.GPIO_Label=RESETn
PA15.Signal=GPIO_Output
PA2.Signal=USART2_TX
PA3.Signal=USART2_RX
PA4.GPIO_Label=DS1_CURSENSE
PA4.Signal=ADC1_IN4
PA5.GPIO_Label=DS2_CURSENSE
PA5.Signal=ADC1_IN5
PA6.GPIO_Label=DS3_CURSENSE
PA6.Signal=ADC1_IN6
PA7.GPIO_Label=DS_VBUS_MEAS
PA7.Signal=ADC1_IN7
PA8.GPIO_Label=PGANG
PA8.Signal=GPIO_Input
PA9.GPIO_Label=I2C_SCL_UI
PA9.Signal=I2C2_SCL
PB0.GPIO_Label=LEDBn
PB0.Signal=S_TIM3_CH3
PB1.GPIO_Label=LEDGn
PB1.Signal=S_TIM3_CH4
PB2.GPIO_Label=HOSTMUX_OEn
PB2.Signal=GPIO_Output
PB3.GPIO_Label=HOSTMUX_SEL
PB3.Signal=GPIO_Output
PB4.GPIO_Label=ST_HUB_VBUS
PB4.Signal=GPIO_Input
PB5.GPIO_Label=EN_VBUSB
PB5.Signal=GPIO_Output
PB6.Signal=I2C1_SCL
PB7.Signal=I2C1_SDA
PB8.GPIO_Label=EN_VBUSA
PB8.Signal=GPIO_Output
PB9.GPIO_Label=SWITCH
PB9.Signal=GPXTI9
PC6.GPIO_Label=LEDRn
PC6.Signal=S_TIM3_CH1

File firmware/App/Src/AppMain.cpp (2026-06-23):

/**
 * @file AppMain.cpp
 * @brief Application entry point and main loop
 * @author s-t-e-f-a-n
 * @date 01.06.2026
 */

#include "AppMain.hpp"
#include "LedDriver.hpp"
#include "HardwareManager.hpp"
#include "HubManager.hpp"
#include "SensorManager.hpp"
#include "ConsoleManager.hpp"
#include "UserInterfaceManager.hpp"
#include "DisplayManager.hpp"
#include "UsbSystem.hpp"
#include "main.h"

extern "C" {
    #include "i2c.h"
    #include "tim.h"
}

// Global pointer definitions
namespace h2h3 {
    DisplayManager* display = nullptr;
    LedDriver* LedDriver::instance = nullptr;
}

extern "C" int _write(int file, char *ptr, int len) {
    h2h3::ConsoleManager::sendBinary(reinterpret_cast<uint8_t*>(ptr), len);
    return len;
}

extern "C" {
    void HAL_TIM_PeriodElapsedCallback(TIM_HandleTypeDef *htim) {
        h2h3::LedDriver::timerCallback(htim);
    }
}

/* -------------------------------------------------------------------------- */
/* APP MAIN										                              */
/* -------------------------------------------------------------------------- */

// Initialize the main controller components
extern "C" void AppMain(void) {
	using namespace h2h3;

	// Intialize console output
	ConsoleManager::init();
    LOG_DEBUG("\r\nSystem starting...\r\n");

	// Initialize hardware
	UpstreamType initialHost = HardwareManager::init();
	LOG_DEBUG("Host detected: %s\r\n", (initialHost == h2h3::UpstreamType::A) ? "A" : "B");

	// Instantiate raw drivers using low-level HAL handles
	static LedDriver statusLed(&htim3, true); 
    static DisplayManager displayInstance(&hi2c2, I2C_ADR);
    
    // Assign global pointer
    display = &displayInstance;
    
    // Ensure we only initialize if the pointer is valid
    if (display != nullptr) {
        display->init();
    }

	// Instantiate objects now, before the loop
	SensorManager sensors;
	static UsbSystem usbSystem(sensors); // Inject sensors into USB system

	// Instantiate Orchestrator (Dependency Injection)
	static UserInterfaceManager uiManager(*display, sensors, usbSystem, statusLed);

	// Start the USB subsystem
	usbSystem.init(initialHost);
	LOG_DEBUG("Host's USB data lines muxed to Hub, Hub started, Host's VBUS Muxed to Downstream Ports\r\n");

    LOG_DEBUG("System initialized. Starting main loop.\r\n");

    // Main control loop
    while (1) {

    	// UI Handling
    	uiManager.processInputs();

    	// Poll sensor data
        sensors.poll();

        // Run the state machine
    	usbSystem.runStateMachine();

		// Update state BEFORE rendering
        uiManager.updateState();

        // Visual Feedback
        uiManager.updateOutputs();

        // Add a small delay to avoid spamming the USB/UART bus
        HAL_Delay(20);
    }
}

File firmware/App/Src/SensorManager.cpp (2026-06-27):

/**
 * @file SensorManager.cpp
 * @brief Manages ADC data acquisition for three V and three I channels
 * @author s-t-e-f-a-n
 * @date 01.06.2026
 */

#include "SensorManager.hpp"
#include "ConsoleManager.hpp"
#include "main.h"

// Define the external handle at file scope so it's accessible to all methods in this file
extern ADC_HandleTypeDef hadc1;

// STM32G0 factory calibration address for internal voltage reference (typically 3.0V baseline)
#define STM32G0_VREFINT_CAL_ADDR ((uint16_t*)0x1FFF75AA)

namespace h2h3 {

    Telemetry SensorManager::currentData = {};

    // --- Persistent Filter States for EMA Smoothing ---
    namespace {
        uint32_t emaVbusA  = 0;
        uint32_t emaVbusB  = 0;
        uint32_t emaVbusDs = 0;
        
        uint32_t emaDs1    = 0;
        uint32_t emaDs2    = 0;
        uint32_t emaDs3    = 0;
    }

    /**
     * @brief Polls all ADC channels, averages noise out via 16x oversampling,
     * and passes raw data through an EMA low-pass filter before physical conversion.
     */
    void SensorManager::poll() {
        constexpr uint32_t kOversampleCount = 16u;
        
        // --- 1. Oversampled Read of VREFINT ---
        uint32_t sumVrefInt = 0;
        for (uint32_t i = 0; i < kOversampleCount; ++i) {
            sumVrefInt += Read_ADC(ADC_CHANNEL_VREFINT);
        }
        uint32_t rawVrefInt = (sumVrefInt + (kOversampleCount / 2u)) / kOversampleCount;
        
        if (rawVrefInt == 0) {
            rawVrefInt = 1485; // Fallback to nominal 12-bit value for 1.212V
        }
        
        const uint32_t factoryVRefMv = 3000u;
        const uint32_t vrefintCal = *STM32G0_VREFINT_CAL_ADDR;
        const uint32_t liveVRefMv = (factoryVRefMv * vrefintCal) / rawVrefInt;

        // --- 2. Oversampled Read of Voltage Channels ---
        uint32_t sumVbusA = 0, sumVbusB = 0, sumVbusDs = 0;
        for (uint32_t i = 0; i < kOversampleCount; ++i) {
            sumVbusA  += Read_ADC(ADC_CHANNEL_0);
            sumVbusB  += Read_ADC(ADC_CHANNEL_1);
            sumVbusDs += Read_ADC(ADC_CHANNEL_7);
        }
        uint32_t rawVbusA  = (sumVbusA  + (kOversampleCount / 2u)) / kOversampleCount;
        uint32_t rawVbusB  = (sumVbusB  + (kOversampleCount / 2u)) / kOversampleCount;
        uint32_t rawVbusDs = (sumVbusDs + (kOversampleCount / 2u)) / kOversampleCount;

        // Apply Heavier EMA Low-Pass Filter (Weight: 93.75% Old / 6.25% New)
        // Formula: (Old * 15 + New) / 16
        emaVbusA  = (emaVbusA  == 0) ? rawVbusA  : ((emaVbusA  * 63u) + rawVbusA)  >> 6;
        emaVbusB  = (emaVbusB  == 0) ? rawVbusB  : ((emaVbusB  * 63u) + rawVbusB)  >> 6;
        emaVbusDs = (emaVbusDs == 0) ? rawVbusDs : ((emaVbusDs * 63u) + rawVbusDs) >> 6;

        currentData.voltage.vbusa_mv  = static_cast<uint16_t>((emaVbusA  * liveVRefMv * kVoltageScale) / kAdcMaxTicks);
        currentData.voltage.vbusb_mv  = static_cast<uint16_t>((emaVbusB  * liveVRefMv * kVoltageScale) / kAdcMaxTicks);
        currentData.voltage.vbusds_mv = static_cast<uint16_t>((emaVbusDs * liveVRefMv * kVoltageScale) / kAdcMaxTicks);

        // --- 3. Oversampled Read of Current Channels ---
        uint32_t sumDs1 = 0, sumDs2 = 0, sumDs3 = 0;
        for (uint32_t i = 0; i < kOversampleCount; ++i) {
            sumDs1 += Read_ADC(ADC_CHANNEL_4);
            sumDs2 += Read_ADC(ADC_CHANNEL_5);
            sumDs3 += Read_ADC(ADC_CHANNEL_6);
        }
        uint32_t rawDs1 = (sumDs1 + (kOversampleCount / 2u)) / kOversampleCount;
        uint32_t rawDs2 = (sumDs2 + (kOversampleCount / 2u)) / kOversampleCount;
        uint32_t rawDs3 = (sumDs3 + (kOversampleCount / 2u)) / kOversampleCount;

        // Apply Heavier EMA Low-Pass Filter (Weight: 93.75% Old / 6.25% New)
        // Formula: (Old * 15 + New) / 16
        emaDs1    = (emaDs1    == 0) ? rawDs1    : ((emaDs1    * 63u) + rawDs1)    >> 6;
        emaDs2    = (emaDs2    == 0) ? rawDs2    : ((emaDs2    * 63u) + rawDs2)    >> 6;
        emaDs3    = (emaDs3    == 0) ? rawDs3    : ((emaDs3    * 63u) + rawDs3)    >> 6;

        const uint32_t liveCurrentMultiplier = (liveVRefMv * 1000000u) / (kAdcMaxTicks * kRShuntMOHm * kAmplifierAv);

        currentData.current.ds1_ma = static_cast<uint16_t>((emaDs1 * liveCurrentMultiplier) / (kCurrentPrecisionScale / 100u));
        currentData.current.ds2_ma = static_cast<uint16_t>((emaDs2 * liveCurrentMultiplier) / (kCurrentPrecisionScale / 100u));
        currentData.current.ds3_ma = static_cast<uint16_t>((emaDs3 * liveCurrentMultiplier) / (kCurrentPrecisionScale / 100u));
    }

    const Telemetry& SensorManager::getTelemetry() {
        return currentData;
    }

    /**
     * @brief Reads a single ADC channel.
     * * Configures the ADC for the specified channel, performs a single-shot
     * conversion, and returns the raw digital value.
     * * @param channel The ADC channel index to read (e.g., ADC_CHANNEL_0).
     * @return uint32_t The raw ADC conversion result, or 0 if conversion fails.
     */
    uint32_t SensorManager::Read_ADC(uint32_t channel) {
        // Force the linker to look in the global scope for the C-variable
        ADC_ChannelConfTypeDef sConfig = {0};
        sConfig.Channel = channel;
        sConfig.Rank = ADC_REGULAR_RANK_1;
        //sConfig.SamplingTime = ADC_SAMPLETIME_39CYCLES_5;
        sConfig.SamplingTime = ADC_SAMPLETIME_160CYCLES_5;

        if (HAL_ADC_ConfigChannel(&::hadc1, &sConfig) != HAL_OK) {
            return 0;
        }

        if (HAL_ADC_Start(&::hadc1) != HAL_OK) {
            return 0;
        }

        uint32_t result = 0;
        if (HAL_ADC_PollForConversion(&::hadc1, 10) == HAL_OK) {
            result = HAL_ADC_GetValue(&::hadc1);
        }
        HAL_ADC_Stop(&::hadc1);
        return result;
    }

    bool SensorManager::isSampleStable(uint32_t sample, uint32_t mean) {
        uint32_t diff = (sample > mean) ? (sample - mean) : (mean - sample);
        uint32_t tolerance = (mean * kStartupStabilityPercent + 50u) / 100u;
        if (tolerance == 0u) {
            tolerance = 1u;
        }
        return diff <= tolerance;
    }

    bool SensorManager::startupSelfTest() {
        constexpr uint32_t channels[] = {
            ADC_CHANNEL_0,
            ADC_CHANNEL_1,
            ADC_CHANNEL_7,
            ADC_CHANNEL_4,
            ADC_CHANNEL_5,
            ADC_CHANNEL_6
        };

        // Calibration
        HAL_ADCEx_Calibration_Start(&hadc1);

        for (uint32_t channel : channels) {
            uint32_t samples[kStartupSampleCount] = {0};
            uint32_t sum = 0;
            uint32_t minValue = UINT32_MAX;
            uint32_t maxValue = 0;

            for (uint8_t i = 0; i < kStartupSampleCount; ++i) {
                samples[i] = Read_ADC(channel);
                sum += samples[i];
                minValue = (samples[i] < minValue) ? samples[i] : minValue;
                maxValue = (samples[i] > maxValue) ? samples[i] : maxValue;
                HAL_Delay(5);
            }
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

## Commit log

2026-06-23 feat: initial release of twinusb hardware, firmware, and enclosure
    [documentation.kicad_sch, twinusb.kicad.kicad_pcb, twinusb.kicad.kicad_sch]
2026-06-27 fix: state machine couldn't handle overload fault correctly fix: host disconnection was not correctly reflected on status header/footer line feat: ADC calibration and sensor value filtering added fea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
    [HardwareManager.cpp, SensorManager.cpp, SensorManager.hpp]

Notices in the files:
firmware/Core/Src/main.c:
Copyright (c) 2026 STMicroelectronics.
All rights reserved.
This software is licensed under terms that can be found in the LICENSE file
